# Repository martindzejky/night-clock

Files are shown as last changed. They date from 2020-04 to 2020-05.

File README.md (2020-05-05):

# Night clock

This was my first electronics projects. The goal was to make a "night" clock that would only turn on after clapping. The display was made from orange LEDs to make it suitable for the night.

The project ended up too much for me at the time. I made a proper schematic with all components and designed the PCB layout for a prototype board in KiCad! I used different layers for solder traces and jumper wires. In the end, however, the layout was too complicated and time-consuming. I should have used way more jumper wires, perhaps even utilize wire wrapping wires.

I also did not test the LED display before I started soldering. It later turned out that those 150 ohm resistors were too little and the LEDs were too bright for a night. However, I am very proud that I got the microphone amplifier to work.

All KiCad project files are included in the repository. Here are a few images.

## Schematic

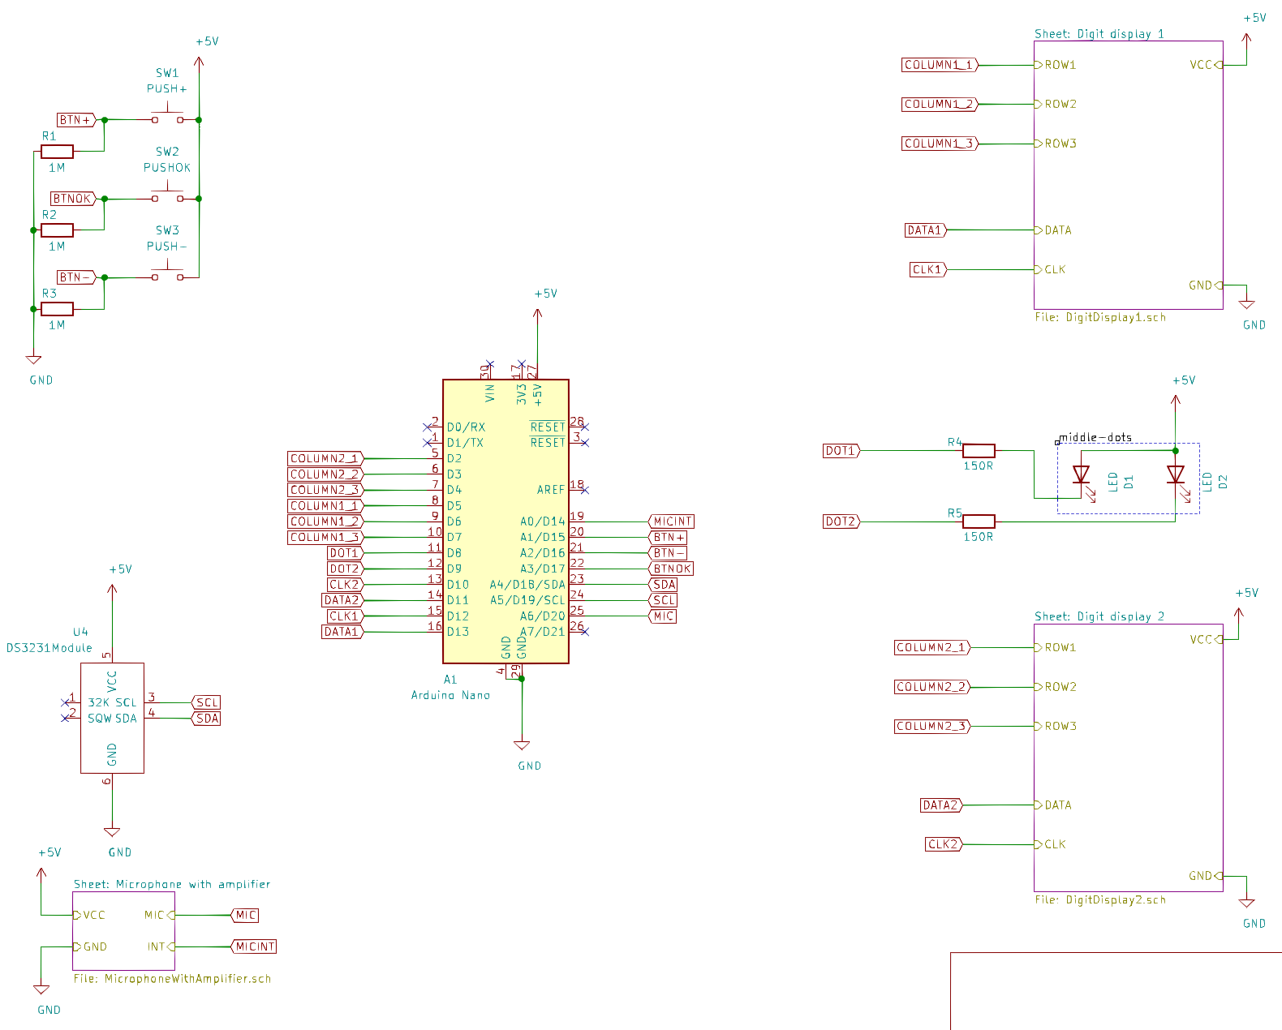
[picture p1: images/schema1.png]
schema 1

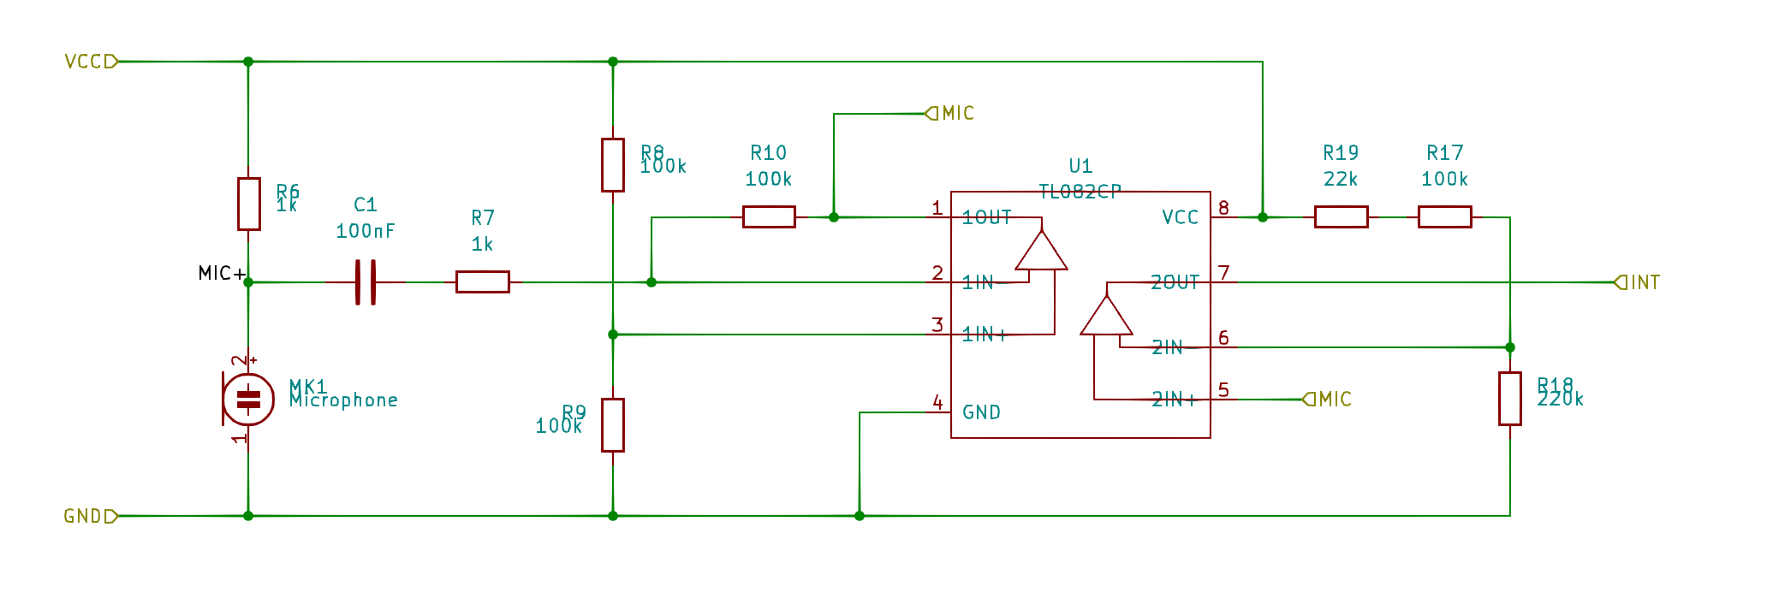
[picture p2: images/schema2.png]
schema 2

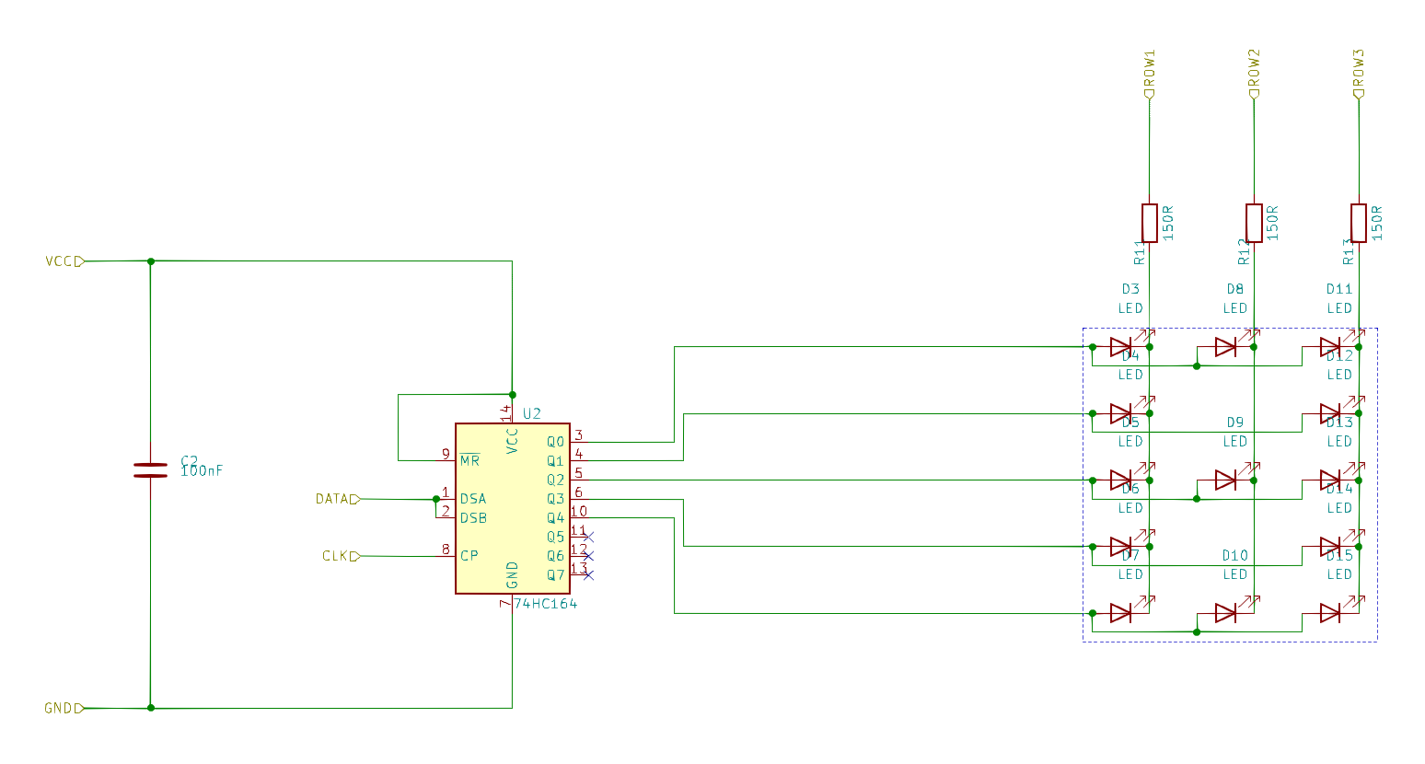
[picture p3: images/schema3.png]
schema 3


## Pcb

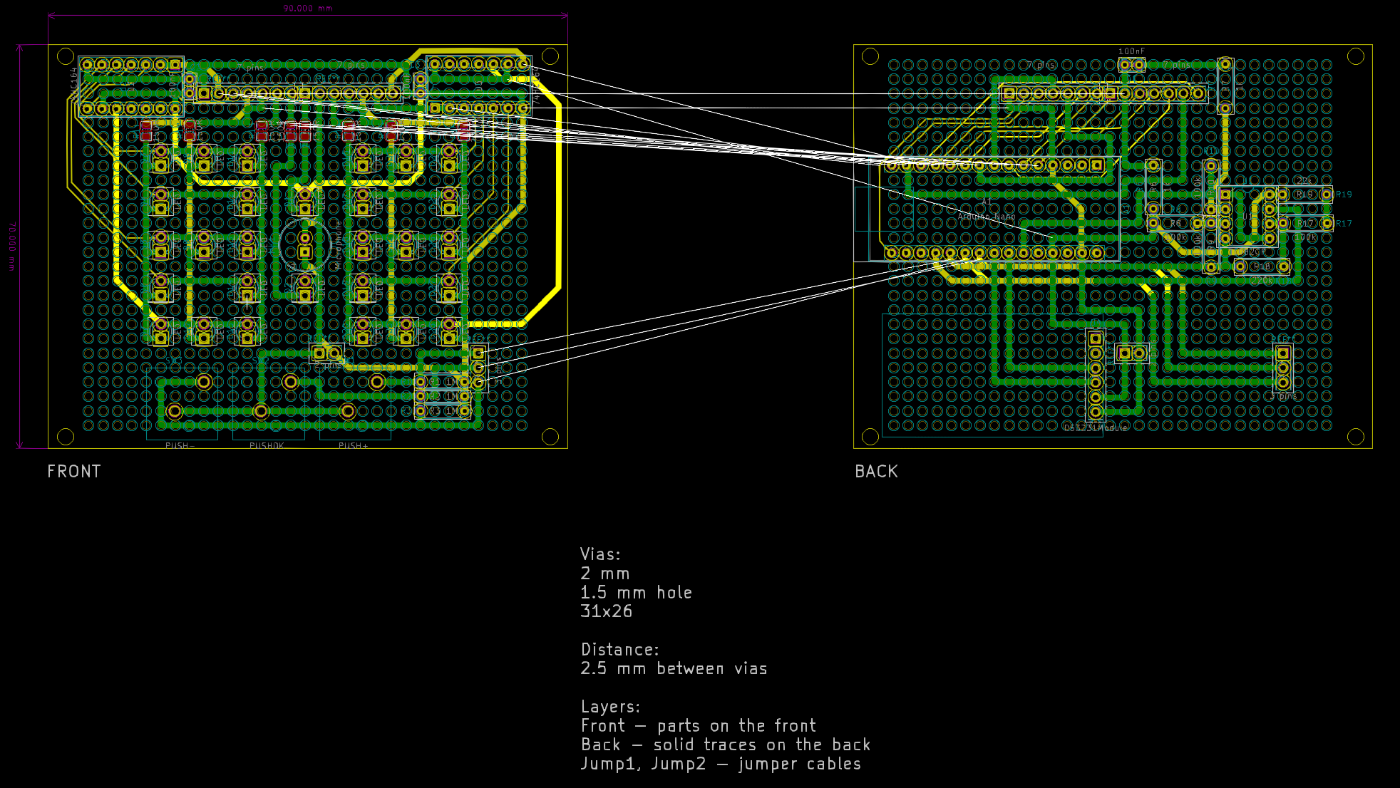
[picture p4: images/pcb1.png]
pcb 1


## Photos

I stopped soldering before I could finish the boards. Here are some progress photos.

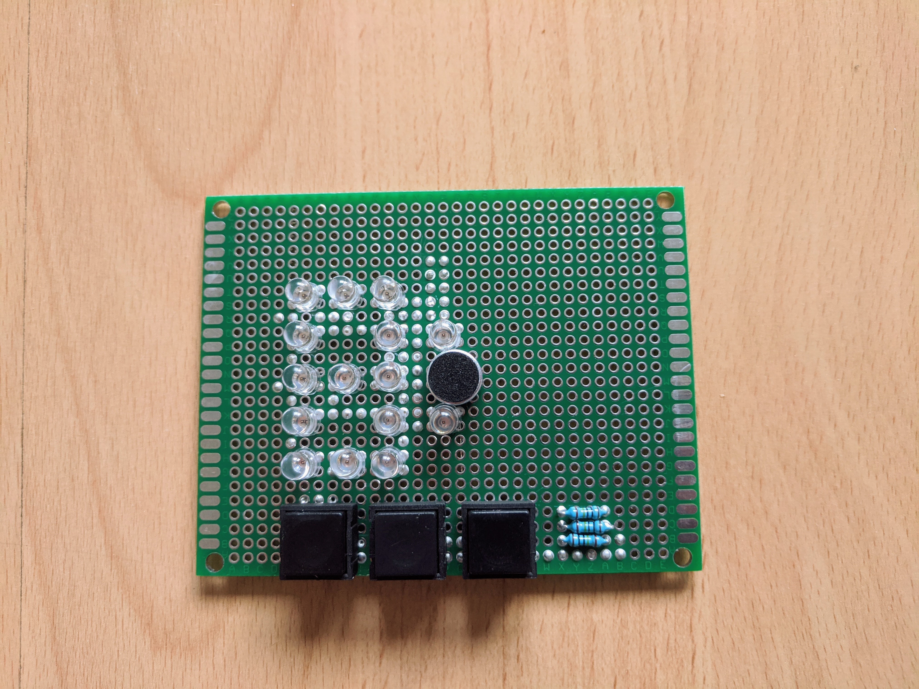
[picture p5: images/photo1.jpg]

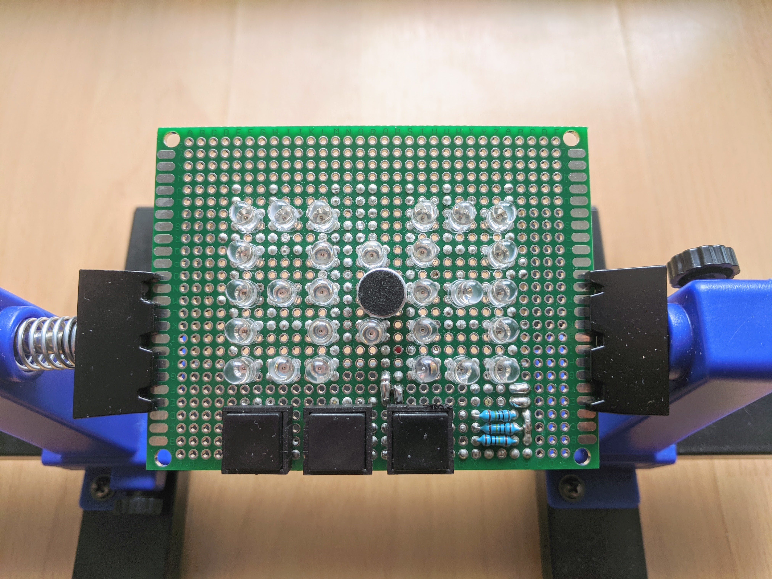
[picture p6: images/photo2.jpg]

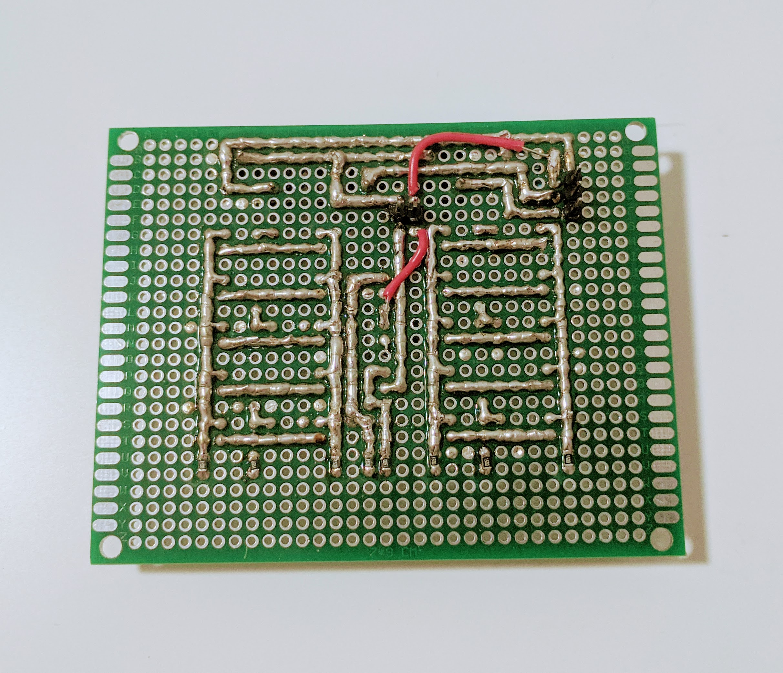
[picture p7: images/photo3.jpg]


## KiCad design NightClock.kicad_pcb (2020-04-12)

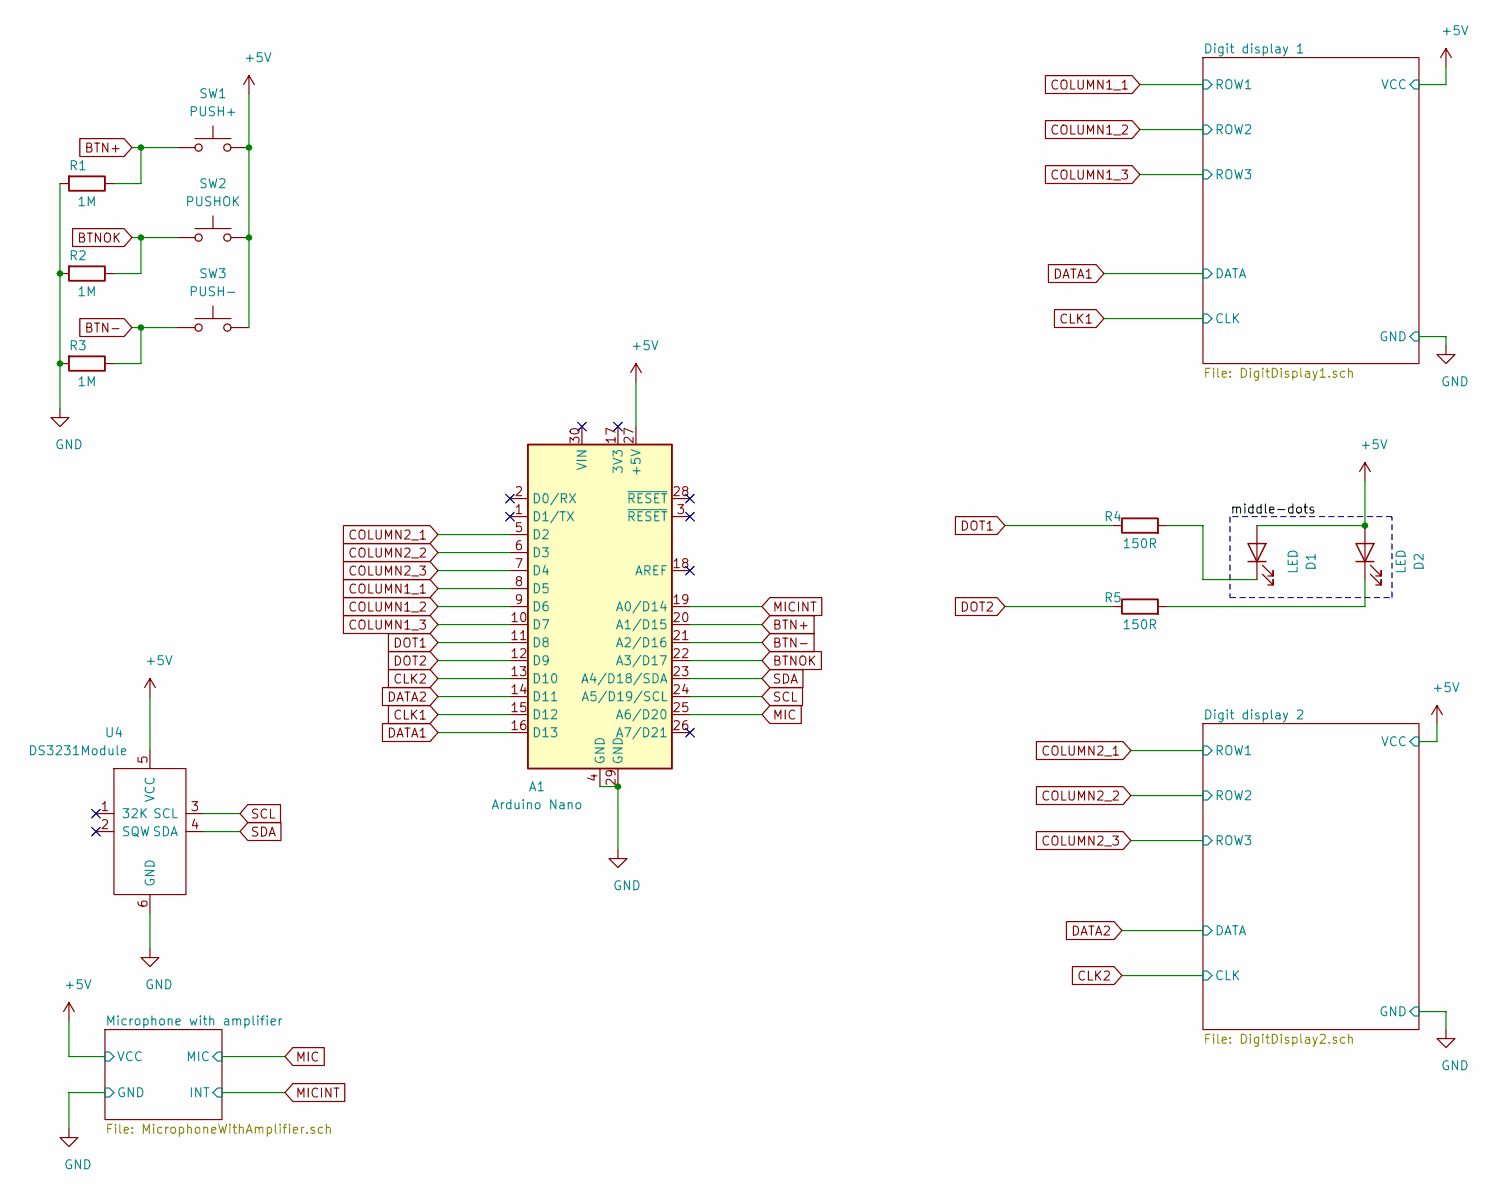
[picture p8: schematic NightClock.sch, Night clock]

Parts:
A1: Arduino Nano; Arduino_Nano
D1, D2: LED; LED_D3.0mm
R1, R2, R3: 1M; R_Axial_DIN0207_L6.3mm_D2.5mm_P7.62mm_Horizontal
R4, R5: 150R; R_0805_2012Metric
SW1: PUSH+; PushButtonBlack
SW2: PUSHOK; PushButtonBlack
SW3: PUSH-; PushButtonBlack
U4: DS3231Module; PinSocket_1x06_P2.54mm_Vertical

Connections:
+5V: A1.27 (+5V), D1.2 (A), D2.2 (A), SW1.2, SW2.2, SW3.2, U4.5 (VCC); also elsewhere on the board
BTN+: A1.20 (A1/D15), R1.1, SW1.1
BTN-: A1.21 (A2/D16), R3.1, SW3.1
BTNOK: A1.22 (A3/D17), R2.1, SW2.1
CLK1: A1.15 (D12); also elsewhere on the board
CLK2: A1.13 (D10); also elsewhere on the board
COLUMN1_1: A1.8 (D5); also elsewhere on the board
COLUMN1_2: A1.9 (D6); also elsewhere on the board
COLUMN1_3: A1.10 (D7); also elsewhere on the board
COLUMN2_1: A1.5 (D2); also elsewhere on the board
COLUMN2_2: A1.6 (D3); also elsewhere on the board
COLUMN2_3: A1.7 (D4); also elsewhere on the board
DATA1: A1.16 (D13); also elsewhere on the board
DATA2: A1.14 (D11); also elsewhere on the board
DOT1: A1.11 (D8), R4.1
DOT2: A1.12 (D9), R5.1
GND: A1.4 (GND), A1.29 (GND), R1.2, R2.2, R3.2, U4.6 (GND); also elsewhere on the board
MIC: A1.25 (A6/D20); also elsewhere on the board
MICINT: A1.19 (A0/D14); also elsewhere on the board
unnamed: D1.1 (K), R4.2
unnamed: D2.1 (K), R5.2
SCL: A1.24 (A5/D19/SCL), U4.3 (SCL)
SDA: A1.23 (A4/D18/SDA), U4.4 (SDA)

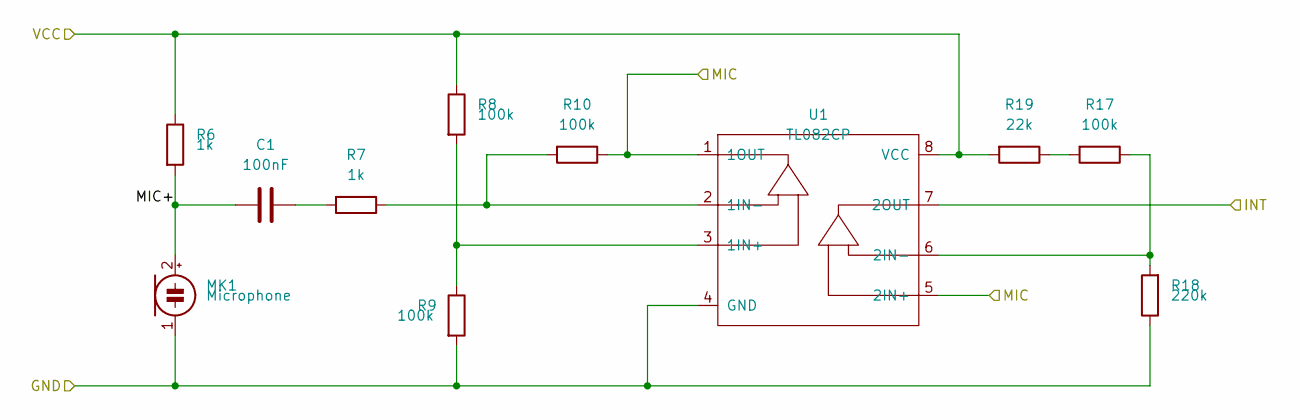
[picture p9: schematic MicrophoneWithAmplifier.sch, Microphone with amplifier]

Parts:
C1: 100nF; C_Disc_D3.4mm_W2.1mm_P2.50mm
MK1: Microphone; CP_Radial_Tantal_D9.0mm_P2.50mm
R6, R7: 1k; R_Axial_DIN0207_L6.3mm_D2.5mm_P7.62mm_Horizontal
R8, R9, R10, R17: 100k; R_Axial_DIN0207_L6.3mm_D2.5mm_P7.62mm_Horizontal
R18: 220k; R_Axial_DIN0207_L6.3mm_D2.5mm_P7.62mm_Horizontal
R19: 22k; R_Axial_DIN0207_L6.3mm_D2.5mm_P7.62mm_Horizontal
U1: TL082CP; DIP-8_W7.62mm_Socket

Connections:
+5V: R6.1, R8.1, R19.2, U1.8 (VCC); also elsewhere on the board
/Microphone with amplifier/MIC+: C1.2, MK1.2 (+), R6.2
GND: MK1.1 (-), R9.2, R18.1, U1.4 (GND); also elsewhere on the board
MIC: R10.1, U1.1 (1OUT), U1.5 (2IN+); also elsewhere on the board
MICINT: U1.7 (2OUT); also elsewhere on the board
unnamed: C1.1, R7.2
unnamed: R8.2, R9.1, U1.3 (1IN+)
unnamed: R7.1, R10.2, U1.2 (1IN-)
unnamed: R17.1, R18.2, U1.6 (2IN-)
unnamed: R17.2, R19.1

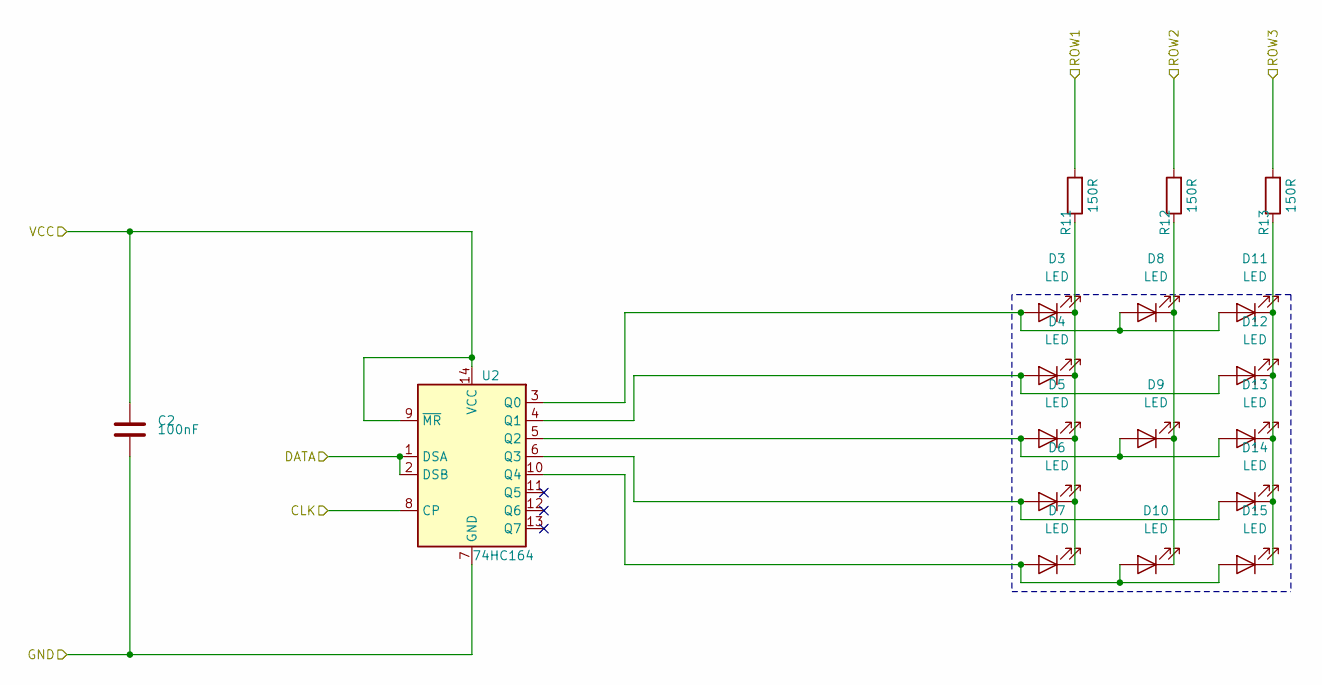
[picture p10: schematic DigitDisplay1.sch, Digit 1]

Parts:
C2: 100nF; C_Disc_D3.4mm_W2.1mm_P2.50mm
D3, D4, D5, D6, D7, D8, D9, D10, D11, D12, D13, D14, D15: LED; LED_D3.0mm
R11, R12, R13: 150R; R_0805_2012Metric
U2: 74HC164; DIP-14_W7.62mm_Socket

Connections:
+5V: C2.1, U2.9 (~MR), U2.14 (VCC); also elsewhere on the board
CLK1: U2.8 (CP); also elsewhere on the board
COLUMN1_1: R11.2; also elsewhere on the board
COLUMN1_2: R12.2; also elsewhere on the board
COLUMN1_3: R13.2; also elsewhere on the board
DATA1: U2.1 (DSA), U2.2 (DSB); also elsewhere on the board
GND: C2.2, U2.7 (GND); also elsewhere on the board
unnamed: D3.1 (K), D4.1 (K), D5.1 (K), D6.1 (K), D7.1 (K), R11.1
unnamed: D8.1 (K), D9.1 (K), D10.1 (K), R12.1
unnamed: D7.2 (A), D10.2 (A), D15.2 (A), U2.10 (Q4)
unnamed: D11.1 (K), D12.1 (K), D13.1 (K), D14.1 (K), D15.1 (K), R13.1
unnamed: D3.2 (A), D8.2 (A), D11.2 (A), U2.3 (Q0)
unnamed: D4.2 (A), D12.2 (A), U2.4 (Q1)
unnamed: D5.2 (A), D9.2 (A), D13.2 (A), U2.5 (Q2)
unnamed: D6.2 (A), D14.2 (A), U2.6 (Q3)

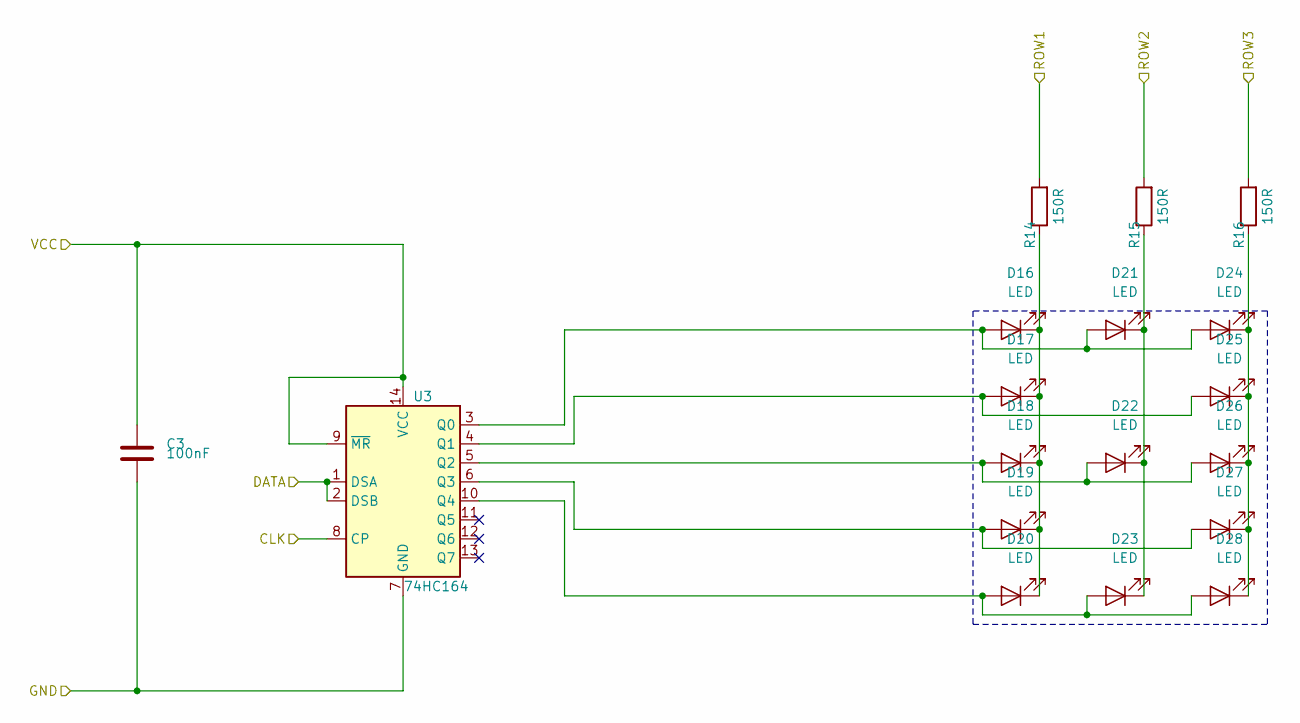
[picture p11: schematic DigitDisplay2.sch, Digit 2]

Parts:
C3: 100nF; C_Disc_D3.4mm_W2.1mm_P2.50mm
D16, D17, D18, D19, D20, D21, D22, D23, D24, D25, D26, D27, D28: LED; LED_D3.0mm
R14, R15, R16: 150R; R_0805_2012Metric
U3: 74HC164; DIP-14_W7.62mm_Socket

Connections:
+5V: C3.1, U3.9 (~MR), U3.14 (VCC); also elsewhere on the board
CLK2: U3.8 (CP); also elsewhere on the board
COLUMN2_1: R14.2; also elsewhere on the board
COLUMN2_2: R15.2; also elsewhere on the board
COLUMN2_3: R16.2; also elsewhere on the board
DATA2: U3.1 (DSA), U3.2 (DSB); also elsewhere on the board
GND: C3.2, U3.7 (GND); also elsewhere on the board
unnamed: D16.1 (K), D17.1 (K), D18.1 (K), D19.1 (K), D20.1 (K), R14.1
unnamed: D16.2 (A), D21.2 (A), D24.2 (A), U3.3 (Q0)
unnamed: D17.2 (A), D25.2 (A), U3.4 (Q1)
unnamed: D18.2 (A), D22.2 (A), D26.2 (A), U3.5 (Q2)
unnamed: D19.2 (A), D27.2 (A), U3.6 (Q3)
unnamed: D20.2 (A), D23.2 (A), D28.2 (A), U3.10 (Q4)
unnamed: D21.1 (K), D22.1 (K), D23.1 (K), R15.1
unnamed: D24.1 (K), D25.1 (K), D26.1 (K), D27.1 (K), D28.1 (K), R16.1

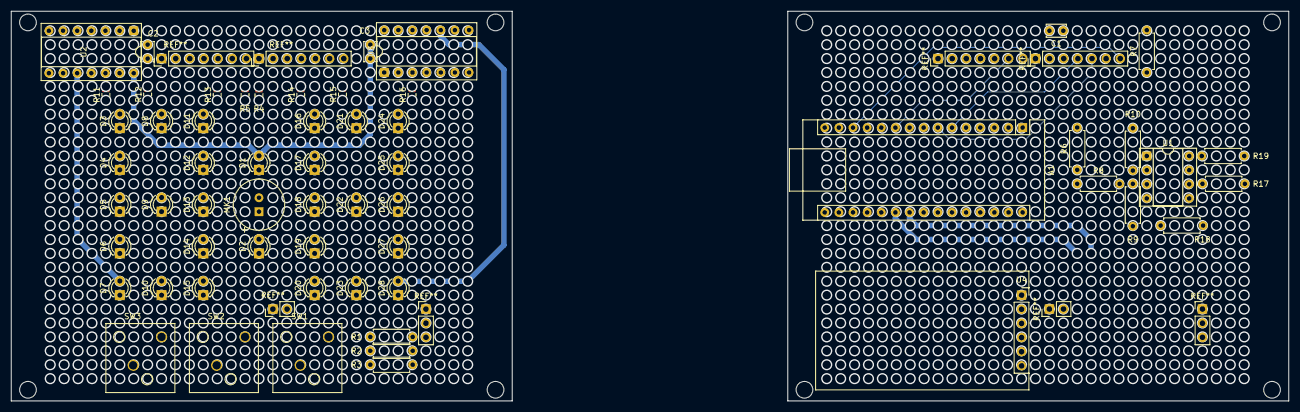
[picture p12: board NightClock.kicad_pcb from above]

Board: 4 copper layers, 229.5 x 70.0 mm, 59 parts (0 on the bottom side), 45 nets.

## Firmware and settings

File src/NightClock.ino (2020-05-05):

#include <Arduino.h>

int maxAudioValue = 0;
int minAudioValue = 1024;
volatile byte message = 0;

void printMessage() {
    message = 1;
}

void printBounds() {
    Serial.print("New bounds: ");
    Serial.print(minAudioValue);
    Serial.print(" ");
    Serial.println(maxAudioValue);
}

void setup() {
    Serial.begin(9600);
    Serial.println("STARTING");

    pinMode(14, INPUT);
    attachInterrupt(8, printMessage, RISING);
    Serial.println("Attached the interrupt handler");
}

void loop() {
    if (message) {
        message = 0;
        Serial.println("Interrupt received!!!");
    }

    int currentAudioValue = analogRead(A6);

    if (currentAudioValue > maxAudioValue) {
        maxAudioValue = currentAudioValue;
        printBounds();
    }

    if (currentAudioValue < minAudioValue) {
        minAudioValue = currentAudioValue;
        printBounds();
    }
}

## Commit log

2020-04-10 add the project schematic
    [DigitDisplay1.sch, DigitDisplay2.sch, MicrophoneWithAmplifier.sch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]
2020-04-11 add a comparator for setting up an interrupt
    [MicrophoneWithAmplifier.sch, NightClock.sch]
2020-04-11 add the RTC module and base prototype pcb layout
    [DigitDisplay1.sch, DigitDisplay2.sch, MicrophoneWithAmplifier.sch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]
2020-04-12 make the pcb design
    [MicrophoneWithAmplifier.sch, NightClock.kicad_pcb, NightClock.sch]
2020-05-05 add simple arduino program for detecting audio levels
